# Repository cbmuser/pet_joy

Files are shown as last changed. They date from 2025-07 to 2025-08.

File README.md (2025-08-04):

# pet_joy

CBM Pet Joystick, Wifi and CB2-Sound

Stupid PET Tricks Single and Dual-Joystick (supports Auto-Fire-Joystick)

Wifi-Modem @2400 Baud (and less) with NTP-Time

CB2-Sound with gain-stage

Wifi- and Joystick-Mode switchable by one jumper

The adapter is connected to the Userport and uses the 8 bit I/Os and the handshake-line for the additional hardware. There are three joystick-ports, a dual-joystick and the "Stupid PET Tricks"-port. The ports, also CB2 used for 1bit-Sound are switchable to the Wifi-modem by a 74LS257 Multiplexer and a jumper. 
It uses the known, modded C64 Wifi-Modem software and a Wemos D1 Mini. It was tested with the second PET board 2001N and a CBM 8296. For the CB2-line a seperate jumper is included to disconnect the LM386 amplifier, because in Wifi-mode it will produce aggy Rx-responses on the audio-line.

>[!CAUTION]
>Use it on your own risc ! - This is open hard- and software.

## Update-Diary
4.8.2025
The again modded firmware for the Wemos D1 Mini was added. It uses like the PETTERM a 2400 Baud lauch. If you want to request and display NTP-time, you can set your timezone "at$tiz=2" for UTC+2. Write this to your setup "at&w" and after connecting to Wifi you can display date and time "at$t".

>[!IMPORTANT]
The C2N Power- and Breakout-Adapter Gerbers were exchanged. The USB-Pinout was wrong, but it's easy to fix. 
````
Look from the back-side to the pins:
GND
B9
A5
B5
A9
GND

Solder the pins:B9 to A5 and B5 to A9. 

````
Sorry for that, it was done in a hurry. 

17.7.25
Added the PETTERM v0.7.0 using the 2400 Baud fix. If it won't work and you struggeling with messy chars, pick up the original release and give it a try. You can adjust the timing in petterm.s, line 618.

15.7.25
The "2400 Baud"-Issue is nearly fixed. The PETTERM bitbanging IRQ lo-timer must be adjusted to the seemingly a touch faster WEMOS D1 Mini. It's in testing and an updated PETTERM for this setup will follow soon.

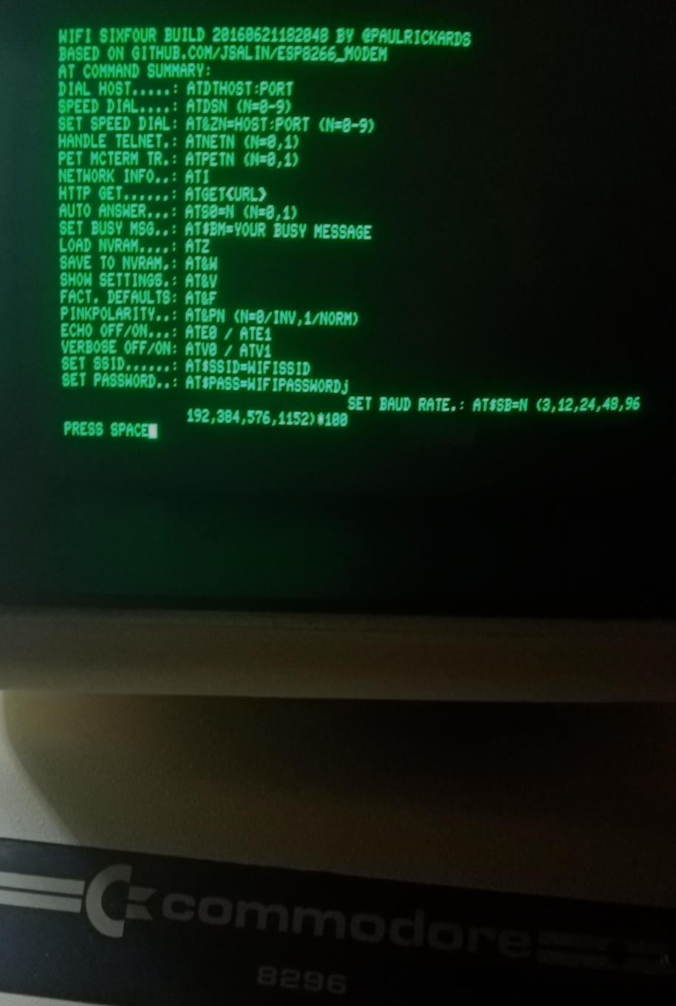
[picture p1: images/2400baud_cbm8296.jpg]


13.7.25
Two adapters: the "horizontal Joystick" and a "C2N-Breakout and Power-Adapter" were added in the adapter-folder. In the ZIPs you'll find Gerber production data.

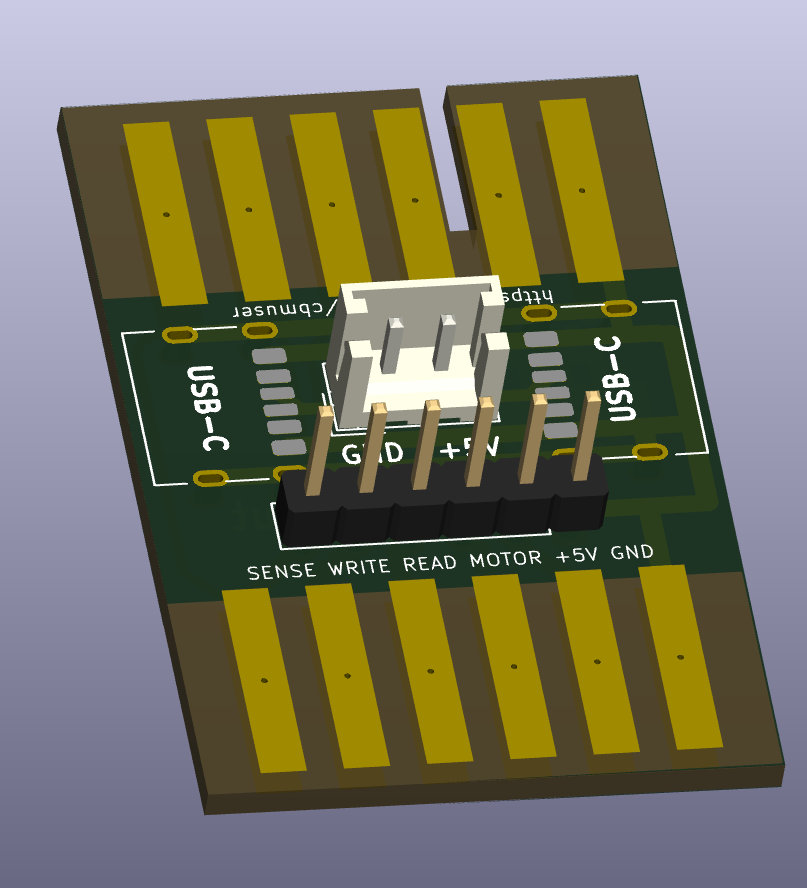
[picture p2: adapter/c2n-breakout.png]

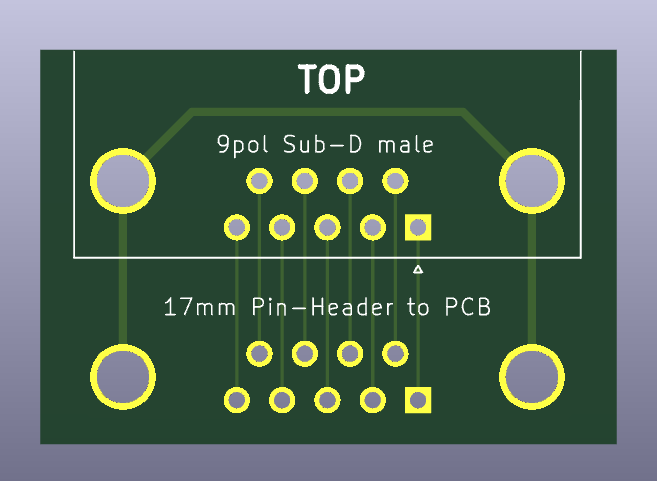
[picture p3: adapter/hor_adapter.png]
 

## Joystick-Ports

<code>
Dual-Joystick
[PA0] UP     ---> Fire
[PA1] DOWN   ---> Fire
[PA2] LEFT
[PA3] RIGHT
[PA4] UP    ---> Fire 
[PA5] DOWN  ---> Fire
[PA6] LEFT
[PA7] RIGHT
Fire (Sub-D Pin 6) is coupled by two ports and two 4148 diodes. 

Stupid PET Tricks (Single Joystick)
[PA0] LEFT
[PA1] RIGHT
[PA2] UP
[PA3] DOWN
[PA4] UNUSED
[PA5] FIRE
[PA6] UNUSED
[PA7] UNUSED
</code>

## CB2-Sound
For driving and decoupling the CB2-Sound a LM386 driver is included. You can adjust the volume by the 10K potentiometer. It is only a small gain-stage (max. x20) to drive a 1 Watt/8Ohm speaker.

## WIFI-Modem
With the Wifi-Modem you'll able to connect your PET to a BBS by Telnet and the PETTERM. It uses the known, modded firmware for the WEMOS D1 NodeMCU. 

## PCB
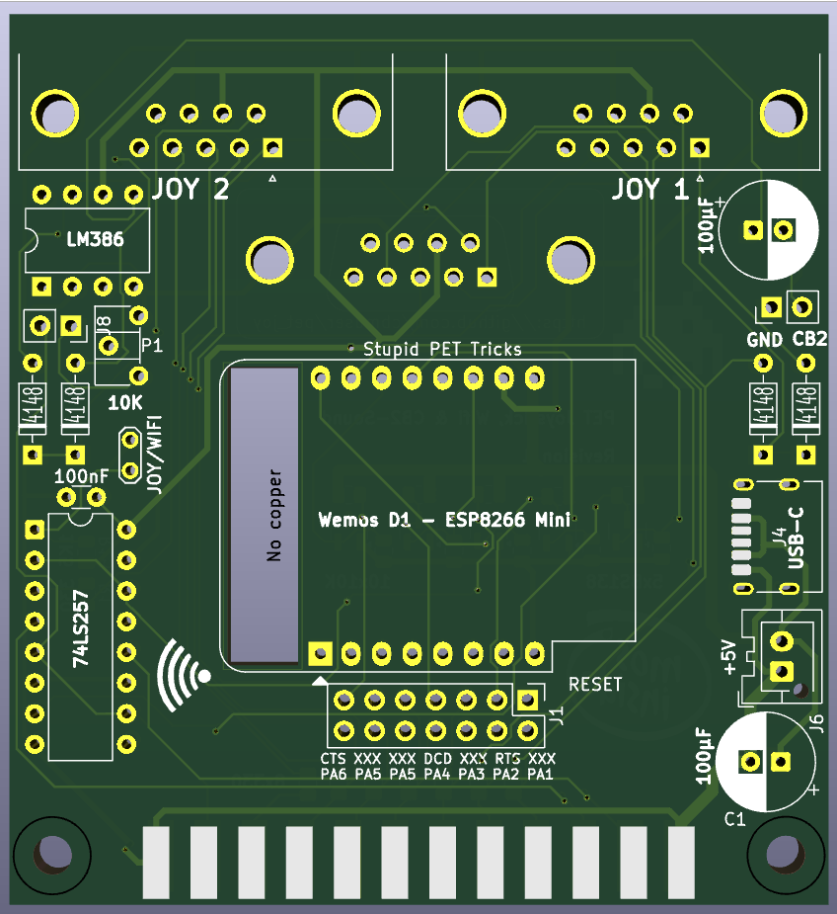
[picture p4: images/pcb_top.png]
PCB


With the JOY/WIFI-Jumper you can swich between Joystick (open) oder Wifi (closed). With the Jumper near the LM386 you can cut the audio-line. On the right, below Joystick#1-port you can connect a small speaker. 

### Parts

#### Bottom

8x BSS138 (SOT-23)

8x 330 Ohm (0805)

10x 10K (0805)

1x Pullup, something between 1,5-2K2 (0805)

#### Top

74LS257 THT/DIP

1x Ceramic Capacitor 100nF THT

4x 4148 DIP

2x 100µF Elko

1x Piher PT6 10K

USB-C 6pol (USB4125-GF-A-0190), JST-connector (+5V round, GND square) or soldered wires for +5V and GND

>[!CAUTION]
>The supply must be 5V+ ! 

2 Jumper and three Pin-headers 2pol

1x Wemos D1 Mini NodeMCU

1x LM386 Audio Amp

2x Sub-D 9pol horizontal, male (print)

1x Sub-D 9pol vertical,male (print)

1x Userport-Connector

## Links

Firmware: http://www.mediafire.com/file/tm71a1oa1a3macc/alwyz_modded_firmware.rar

PETTERM: https://github.com/ChartreuseK/PETTERM

### Games
Old: https://archive.org/details/softwarelibrary_pet or https://portcommodore.com/files/petfiles.htm

New: https://itch.io/games/tag-commodore-pet

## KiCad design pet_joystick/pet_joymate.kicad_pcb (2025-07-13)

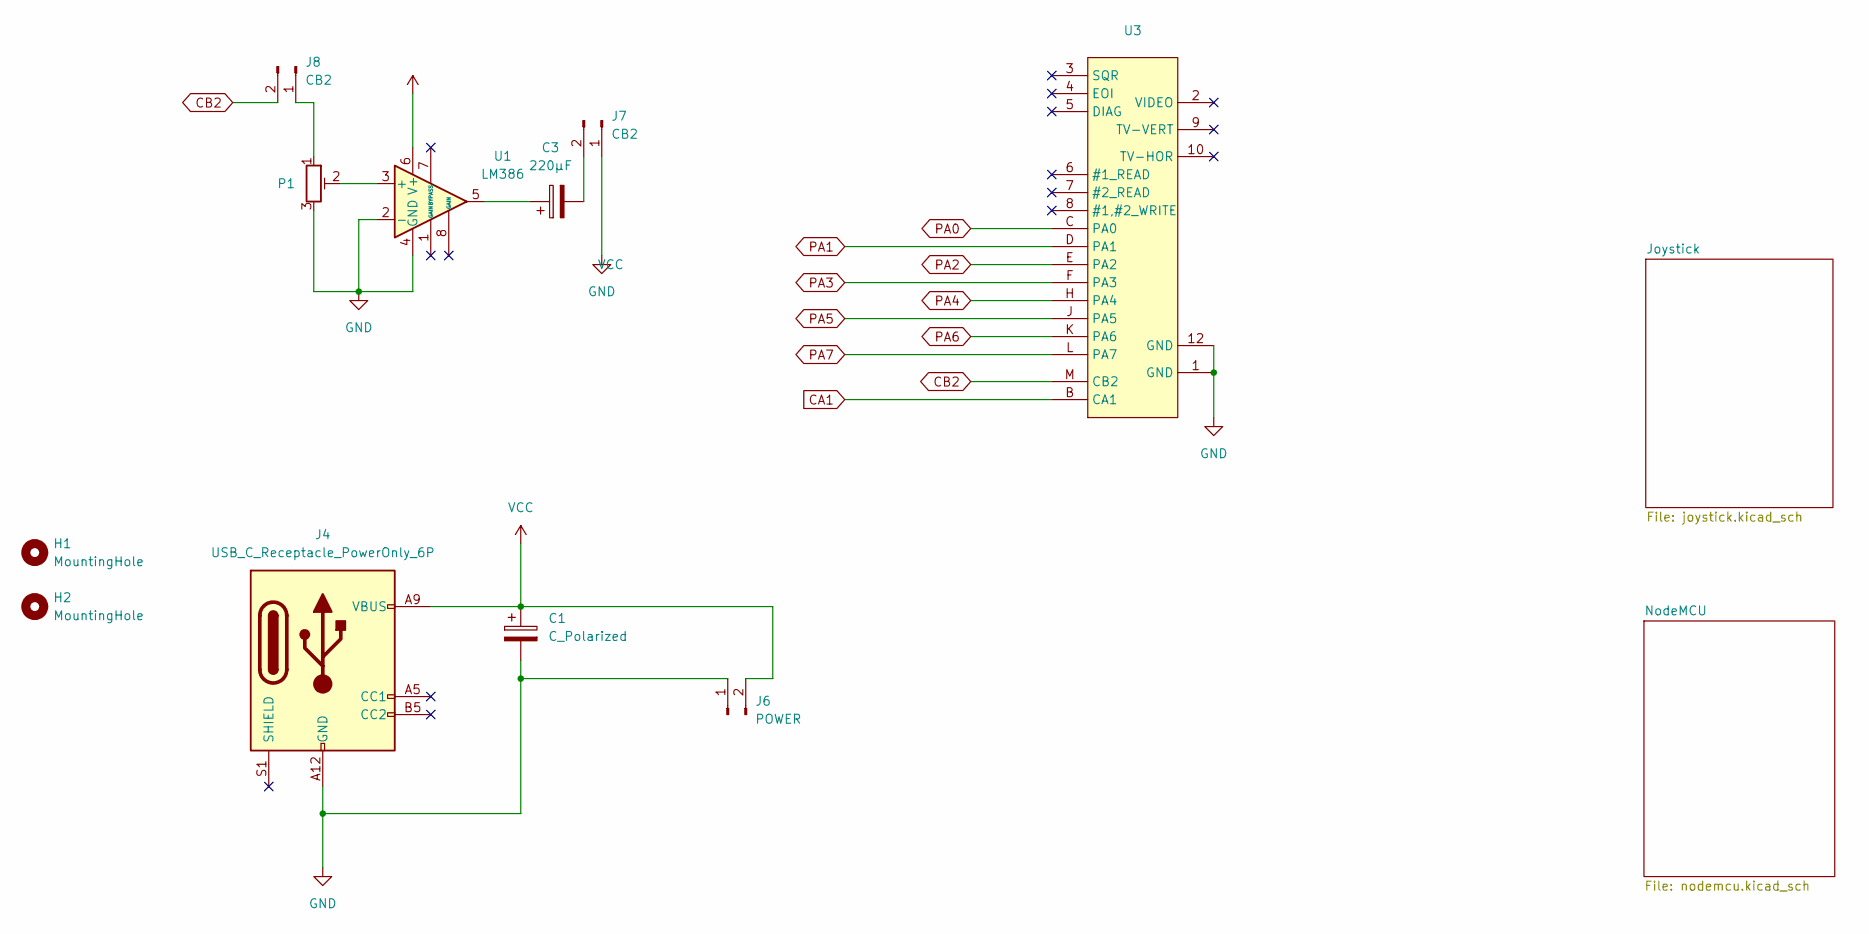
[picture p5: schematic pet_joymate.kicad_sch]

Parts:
C1: C_Polarized; CP_Radial_D8.0mm_P2.50mm
C3: 220µF; CP_Radial_D8.0mm_P2.50mm
H1, H2: MountingHole; MountingHole_3.2mm_M3
J4: USB_C_Receptacle_PowerOnly_6P; USB_C_Receptacle_HRO_TYPE-C-31-M-17
J6: POWER; JST_XA_B02B-XASK-1-A_1x02_P2.50mm_Vertical
J7: CB2; PinHeader_1x02_P2.54mm_Vertical
J8: CB2; PinSocket_1x02_P2.54mm_Vertical
P1: R_Potentiometer_Trim; Potentiometer_Piher_PT-6-H_Horizontal
U1: LM386; DIP-8_W7.62mm
U3: C64-User-Port-Female

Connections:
CA1: U3.B (CA1); also elsewhere on the board
CB2: J8.2, U3.M (CB2); also elsewhere on the board
GND: C1.2, J4.A12 (GND), J4.B12 (GND), J6.1, J7.1, P1.3, U1.2 (-), U1.4 (GND), U3.1 (GND), U3.12 (GND); also elsewhere on the board
unnamed: C3.1, U1.5
unnamed: C3.2, J7.2
unnamed: J8.1, P1.1
unnamed: P1.2, U1.3 (+)
PA0: U3.C (PA0); also elsewhere on the board
PA1: U3.D (PA1); also elsewhere on the board
PA2: U3.E (PA2); also elsewhere on the board
PA3: U3.F (PA3); also elsewhere on the board
PA4: U3.H (PA4); also elsewhere on the board
PA5: U3.J (PA5); also elsewhere on the board
PA6: U3.K (PA6); also elsewhere on the board
PA7: U3.L (PA7); also elsewhere on the board
VCC: C1.1, J4.A9 (VBUS), J4.B9 (VBUS), J6.2, U1.6 (V+); also elsewhere on the board

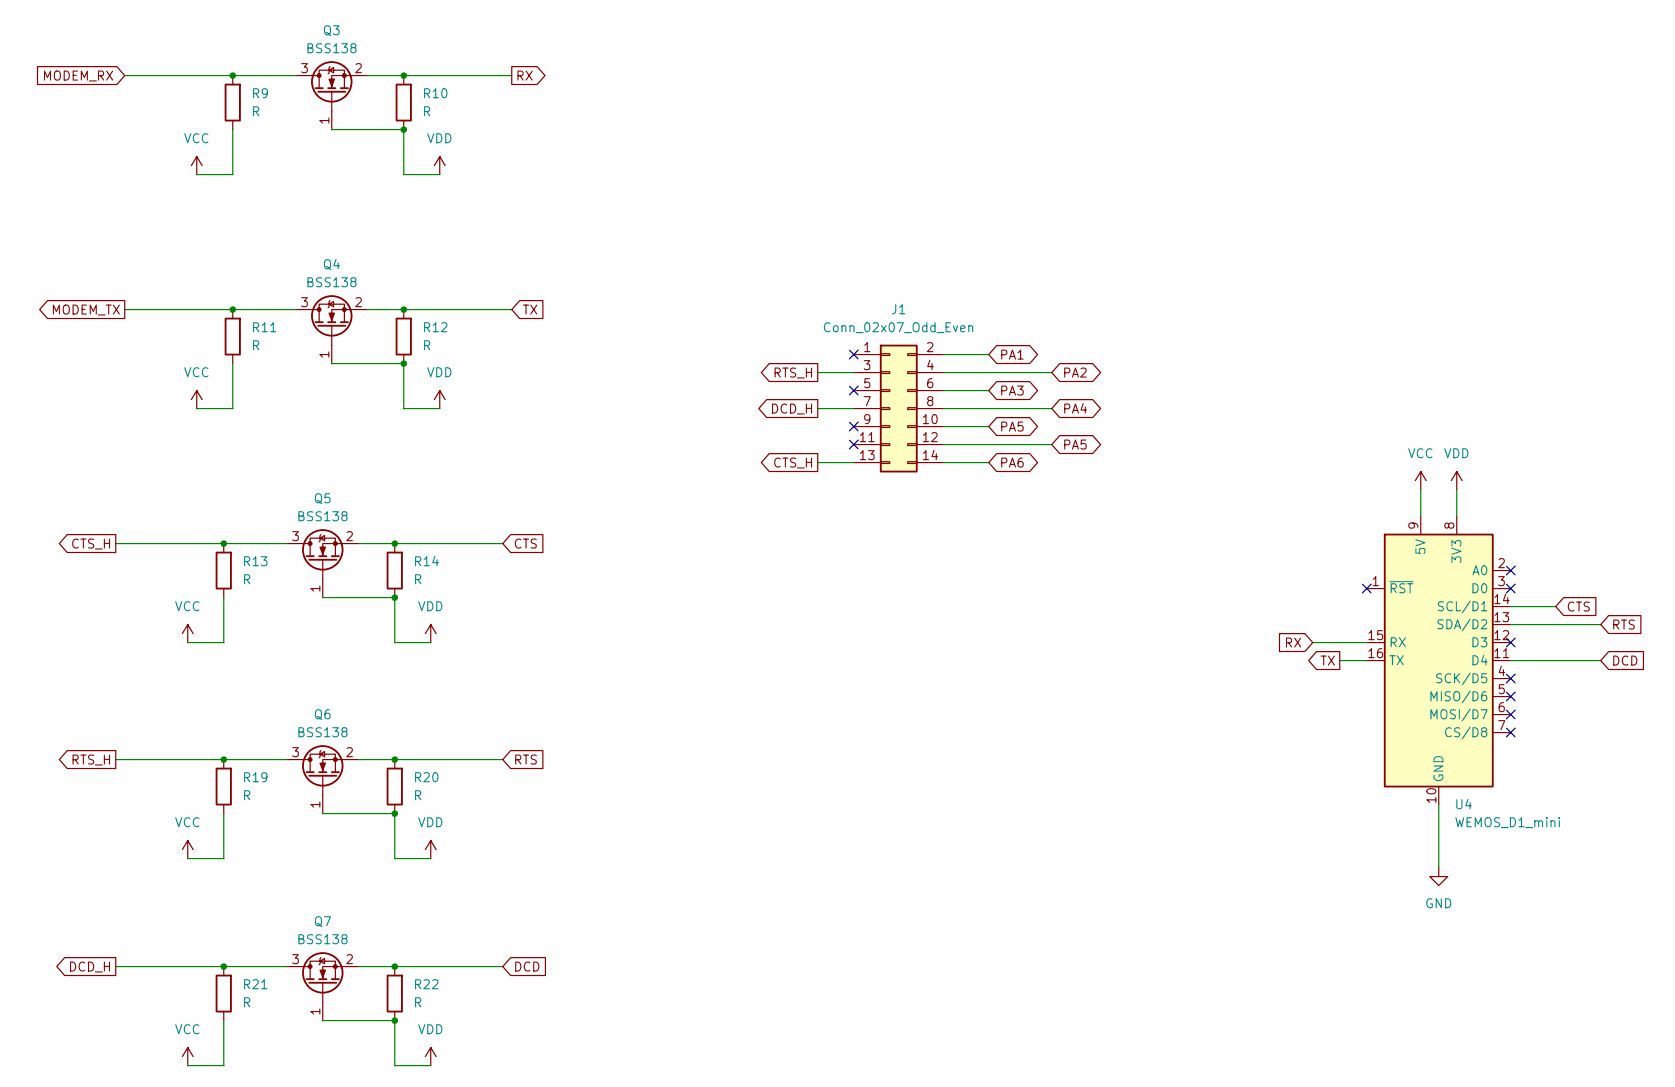
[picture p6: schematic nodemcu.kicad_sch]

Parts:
J1: Conn_02x07_Odd_Even; PinHeader_2x07_P2.54mm_Vertical
Q3, Q4, Q5, Q6, Q7: BSS138; SOT-23
R9, R10, R11, R12, R13, R14, R19, R20, R21, R22: R; R_0805_2012Metric
U4: WEMOS_D1_mini; WEMOS_D1_mini_light

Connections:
CTS: Q5.2 (S), R14.2, U4.14 (SCL/D1)
CTS_H: J1.13, Q5.3 (D), R13.2
DCD: Q7.2 (S), R22.2, U4.11 (D4)
DCD_H: J1.7, Q7.3 (D), R21.2
GND: U4.10 (GND); also elsewhere on the board
MODEM_RX: Q3.3 (D), R9.2; also elsewhere on the board
MODEM_TX: Q4.3 (D), R11.2; also elsewhere on the board
PA1: J1.2; also elsewhere on the board
PA2: J1.4; also elsewhere on the board
PA3: J1.6; also elsewhere on the board
PA4: J1.8; also elsewhere on the board
PA5: J1.10, J1.12; also elsewhere on the board
PA6: J1.14; also elsewhere on the board
RTS: Q6.2 (S), R20.2, U4.13 (SDA/D2)
RTS_H: J1.3, Q6.3 (D), R19.2
RX: Q3.2 (S), R10.2, U4.15 (RX)
TX: Q4.2 (S), R12.2, U4.16 (TX)
VCC: R9.1, R11.1, R13.1, R19.1, R21.1, U4.9 (5V); also elsewhere on the board
VDD: Q3.1 (G), Q4.1 (G), Q5.1 (G), Q6.1 (G), Q7.1 (G), R10.1, R12.1, R14.1, R20.1, R22.1, U4.8 (3V3)

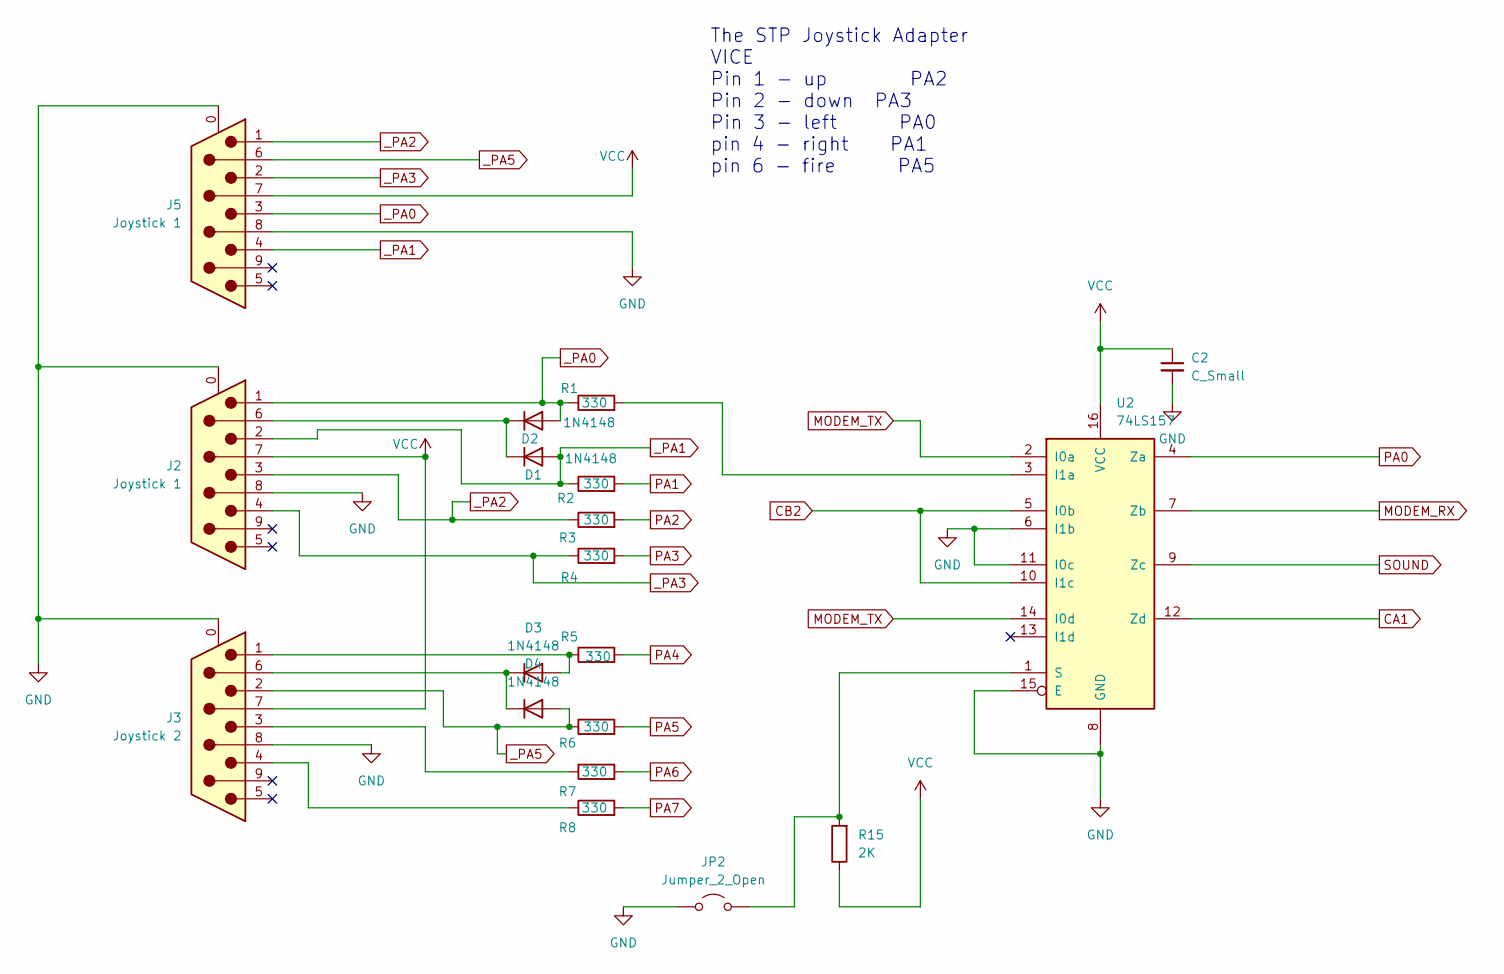
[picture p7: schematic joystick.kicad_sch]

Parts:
C2: C_Small; C_Disc_D3.0mm_W1.6mm_P2.50mm
D1, D2, D3, D4: 1N4148; D_DO-35_SOD27_P7.62mm_Horizontal
J2: Joystick 1; DSUB-9_Male_Horizontal_P2.77x2.84mm_EdgePinOffset4.94mm_Hou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
J3: Joystick 2; DSUB-9_Male_Horizontal_P2.77x2.84mm_EdgePinOffset4.94mm_Hou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
J5: Joystick 1; DSUB-9_Female_Vertical_P2.77x2.84mm_MountingHoles
JP2: Jumper_2_Open; TestPoint_2Pads_Pitch2.54mm_Drill0.8mm
R1, R2, R3, R4, R5, R6, R7, R8: 330; R_0805_2012Metric
R15: 2K; R_0805_2012Metric
U2: 74LS157; DIP-16_W7.62mm

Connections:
CA1: U2.12 (Zd); also elsewhere on the board
CB2: U2.5 (I0b), U2.10 (I1c); also elsewhere on the board
GND: C2.2, J2.0 (PAD), J2.8, J3.0 (PAD), J3.8, J5.0 (PAD), J5.8, JP2.1 (A), U2.6 (I1b), U2.8 (GND), U2.11 (I0c), U2.15 (E); also elsewhere on the board
MODEM_RX: U2.7 (Zb); also elsewhere on the board
MODEM_TX: U2.2 (I0a), U2.14 (I0d); also elsewhere on the board
unnamed: D1.1 (K), D2.1 (K), J2.6
unnamed: D3.2 (A), J3.1, R5.1
unnamed: D3.1 (K), D4.1 (K), J3.6
unnamed: J3.3, R7.1
unnamed: J3.4, R8.1
unnamed: JP2.2 (B), R15.2, U2.1 (S)
unnamed: R1.2, U2.3 (I1a)
PA0: U2.4 (Za); also elsewhere on the board
PA1: R2.2; also elsewhere on the board
PA2: R3.2; also elsewhere on the board
PA3: R4.2; also elsewhere on the board
PA4: R5.2; also elsewhere on the board
PA5: R6.2; also elsewhere on the board
PA6: R7.2; also elsewhere on the board
PA7: R8.2; also elsewhere on the board
SOUND: U2.9 (Zc)
VCC: C2.1, J2.7, J3.7, J5.7, R15.1, U2.16 (VCC); also elsewhere on the board
_PA0: D2.2 (A), J2.1, J5.3, R1.1
_PA1: D1.2 (A), J2.2, J5.4, R2.1
_PA2: J2.3, J5.1, R3.1
_PA3: J2.4, J5.2, R4.1
_PA5: D4.2 (A), J3.2, J5.6, R6.1

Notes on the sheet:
The STP Joystick Adapter VICE Pin 1 - up PA2 Pin 2 - down PA3 Pin 3 - left PA0 pin 4 - right PA1 pin 6 - fire PA5

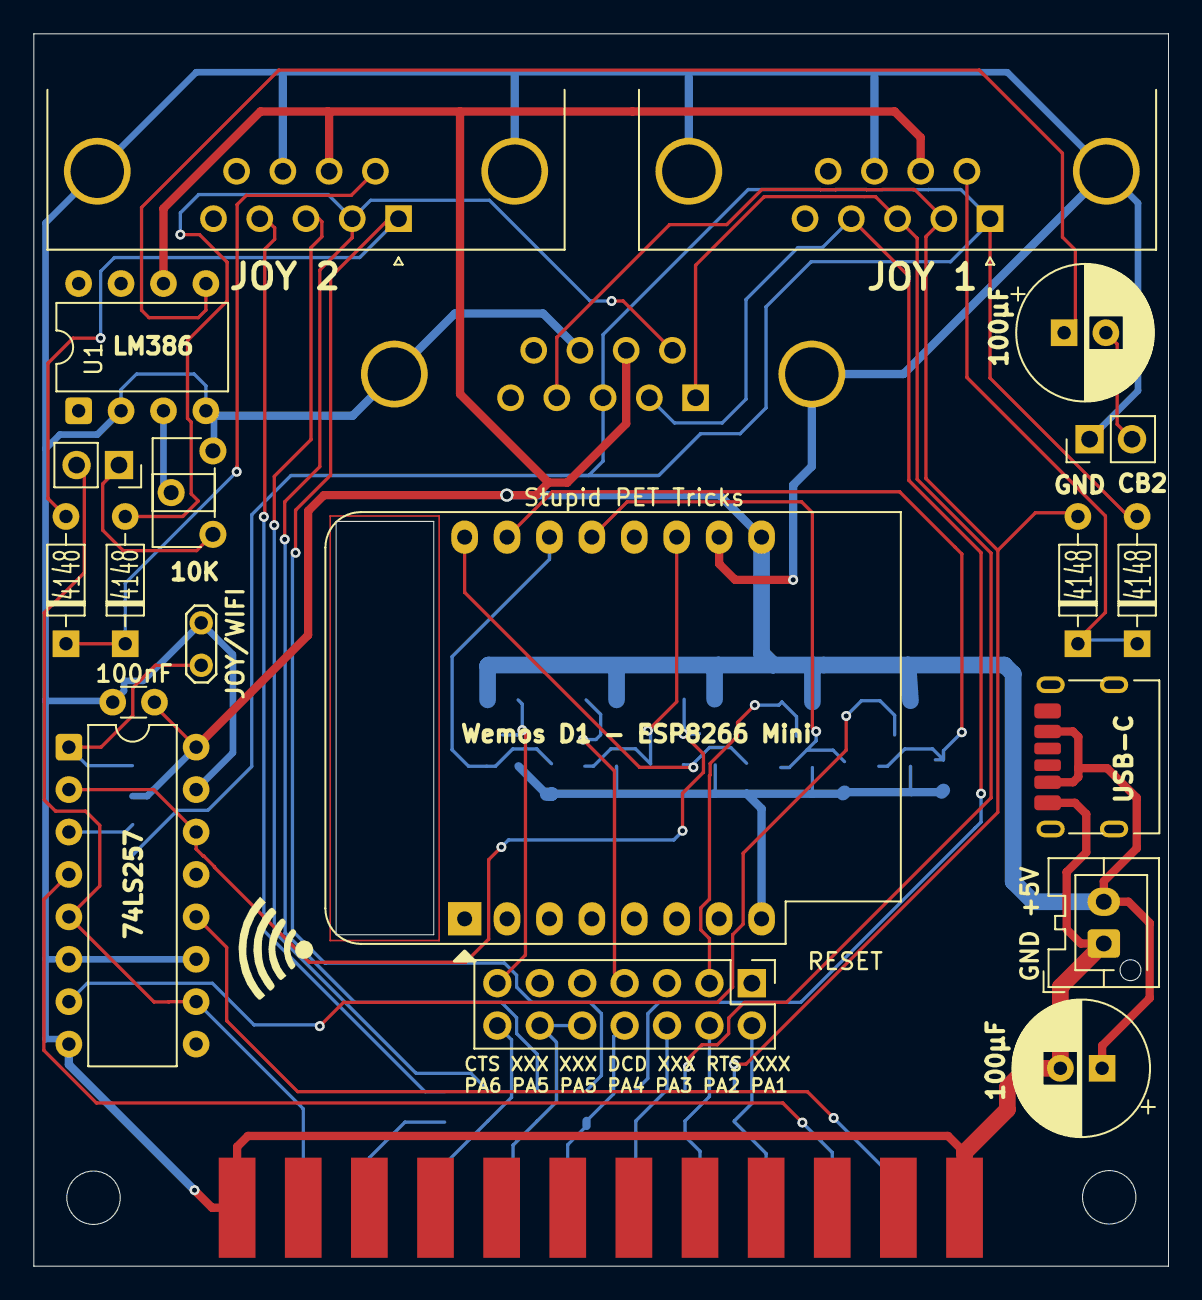
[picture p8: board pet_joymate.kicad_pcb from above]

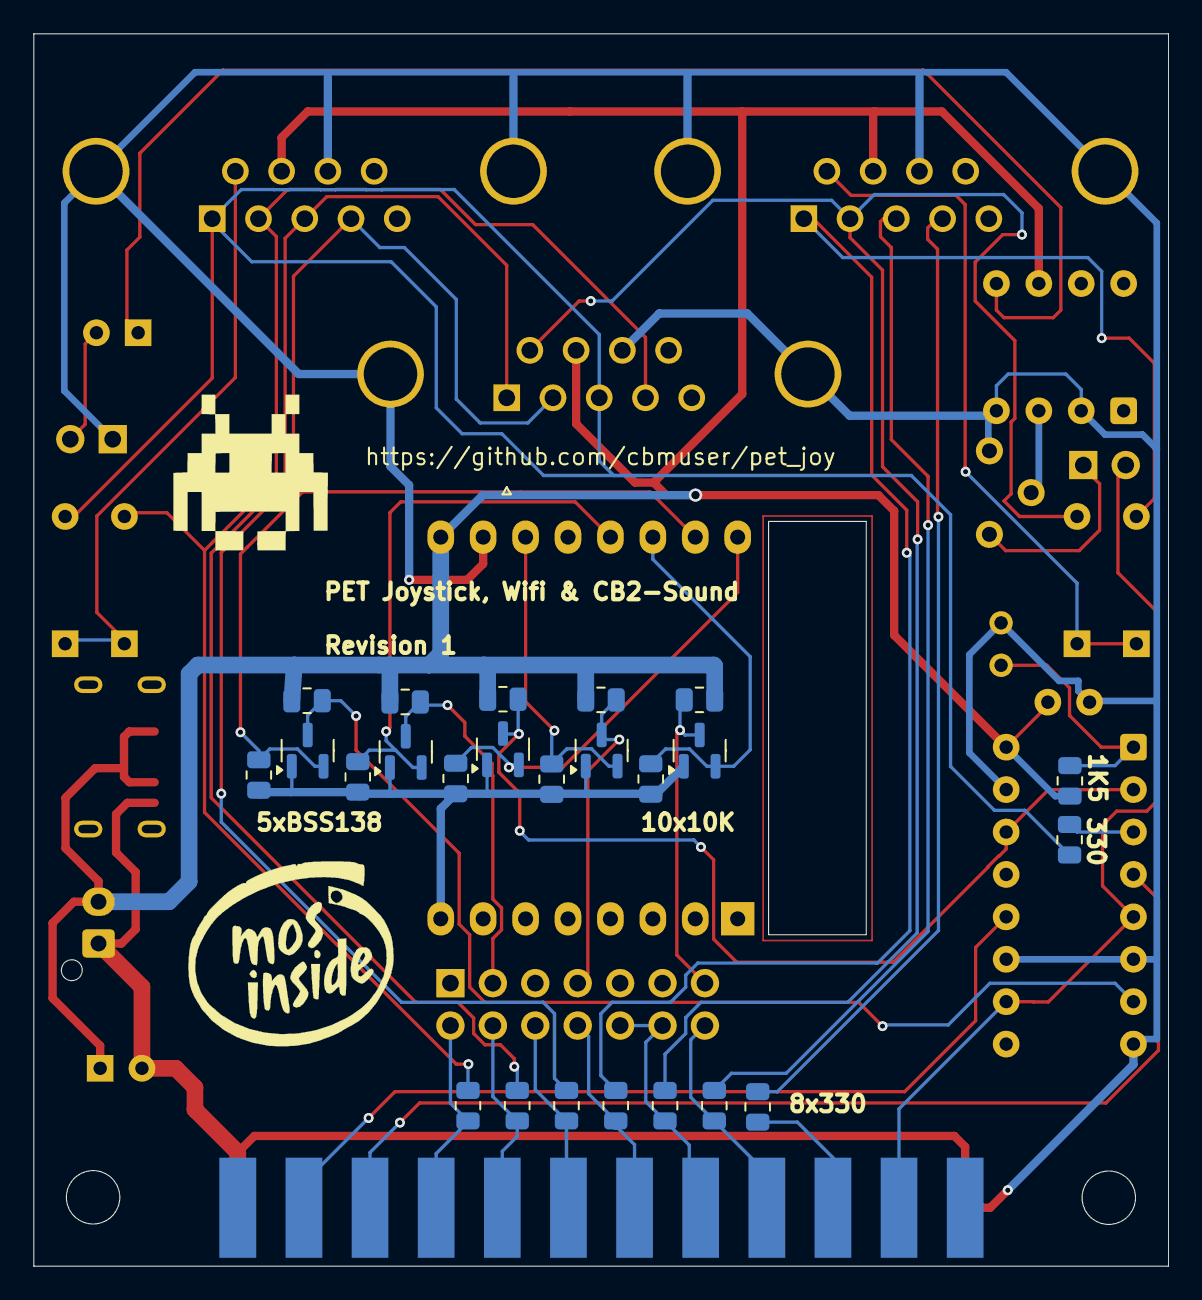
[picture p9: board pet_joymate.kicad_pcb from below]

Board: 2 copper layers, 67.9 x 73.8 mm, 47 parts (25 on the bottom side), 39 nets.

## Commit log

2025-07-06 KiCad and Gerber
    [joystick.kicad_sch, nodemcu.kicad_sch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]
2025-07-06 Games for the Dual-Joystickport
    [joystick.kicad_sch, nodemcu.kicad_sch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]
2025-07-07 Delete images/pcb.png
    minor change
2025-07-07 Images
    minor change in silkscreen
2025-07-07 Kicad and Gerber
    typo in silkscreen: bs138 to bss138
    [joystick.kicad_sch, nodemcu.kicad_sch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]
2025-07-13 Gerber
    C2N-Breakout and RS232 horizontal
2025-07-13 KiCad and Gerber
    Revision 1a
    [joystick.kicad_sch, nodemcu.kicad_sch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]
2025-07-15 C2N-Breakout and Power
2025-07-15 C2N Breakout and Power - Gerber
2025-07-15 Joystick-Adapter horizontal - Gerber
2025-07-15 Adapter for horizontal Joystick-Assembly
2025-08-04 C2N Breakout and Power
    Fixed USB-Pinout
2025-08-04 Wemos D1 Mini Firmware (2400 Baud launch)
    [joystick.kicad_sch, nodemcu.kicad_sch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]
